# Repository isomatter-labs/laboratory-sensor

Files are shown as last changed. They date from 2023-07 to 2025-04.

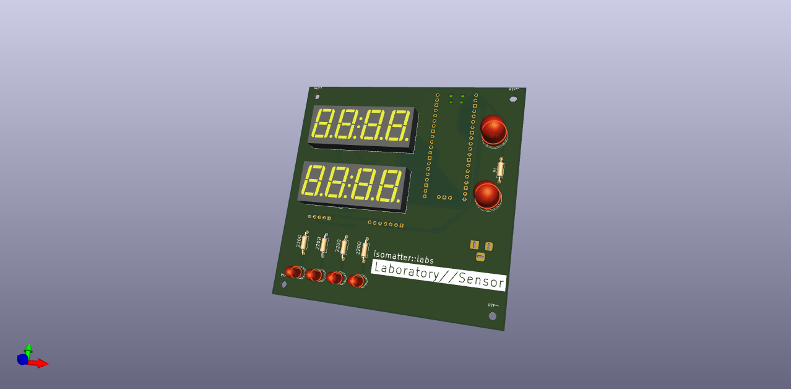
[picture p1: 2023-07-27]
hardware/printed_circuit_board/render.png

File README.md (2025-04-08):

# isomatter-labs :: Laboratory Sensor

## Software
### Building
To build the firmware for the Laboratory Sensor, execute the following:
```sh
cd build
./build.sh
```

### Flashing
After building, there should be a `.uf2` file that can be dragged-and-dropped into a Raspberry Pi Pico.
This is the entirety of the firmware, and requires no additional steps.

## Electronics
### Editing
KiCAD files can be found in `hardware/printed_circuit_board/kicad_files`,
and can be edited or modified to provide any changes you wish to the hardware or layout.

(note that changing the overall footprint of the PCB will likely require changes to the enclosure files)

### Printing
Many PCB-printing services require only `gbr` files, which can be found at
`hardware/printed_circuit_board/gbr_files`.

These files can also be re-generated using the above mentioned KiCAD files and a working copy of KiCAD.

## Enclosure
Included in `hardware/enclosure` are a series of `.step` files, with one file per part.
These files can be sliced by most, if not all, slicers, and are a bit more resilient to paywalling by various CAD editors.

Also included is a file `render.png`, which should give a good idea of what the parts should look like,
and how they should fit together to form the enclosure.

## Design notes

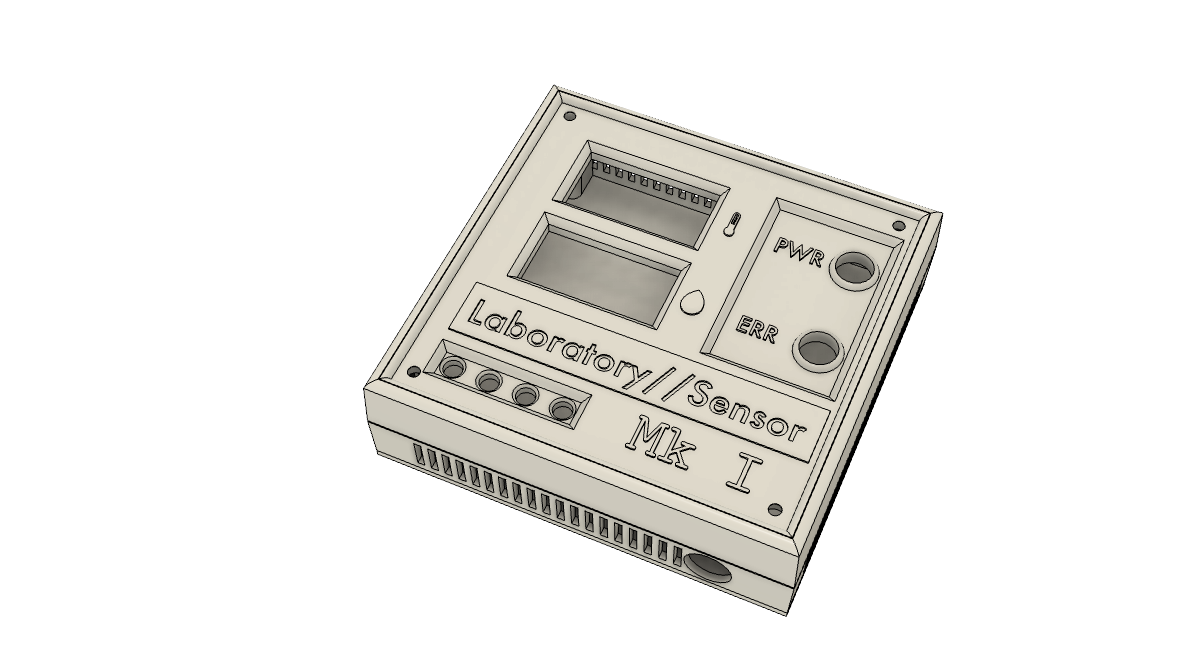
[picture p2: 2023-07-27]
hardware/enclosure/render.png

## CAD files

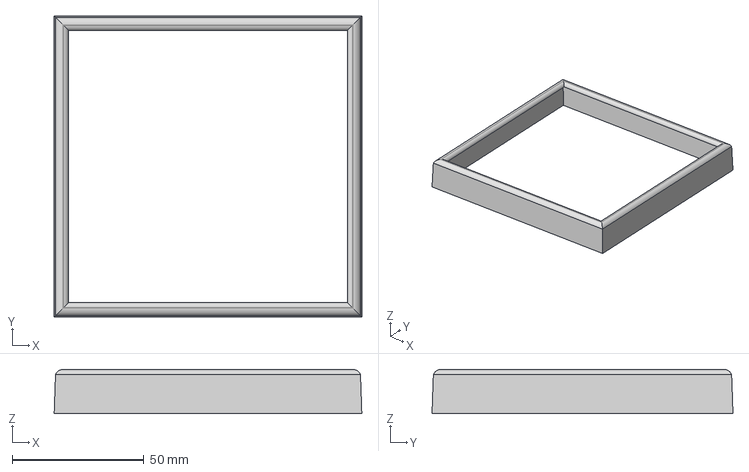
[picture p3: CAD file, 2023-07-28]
hardware/enclosure/case-top.step
116.7 x 114.2 x 16.8 mm

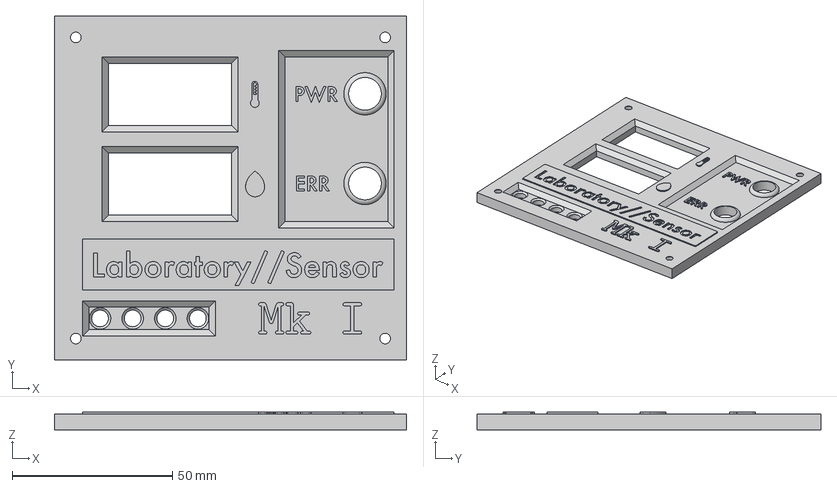
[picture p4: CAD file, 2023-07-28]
hardware/enclosure/faceplate.step
109.7 x 107.1 x 5.50 mm

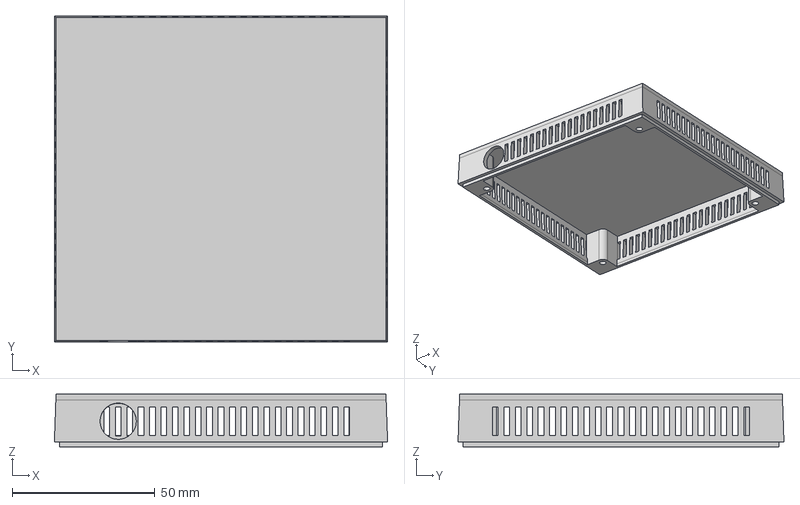
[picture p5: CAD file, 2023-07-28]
hardware/enclosure/case-bottom.step
116.7 x 114.2 x 18.5 mm

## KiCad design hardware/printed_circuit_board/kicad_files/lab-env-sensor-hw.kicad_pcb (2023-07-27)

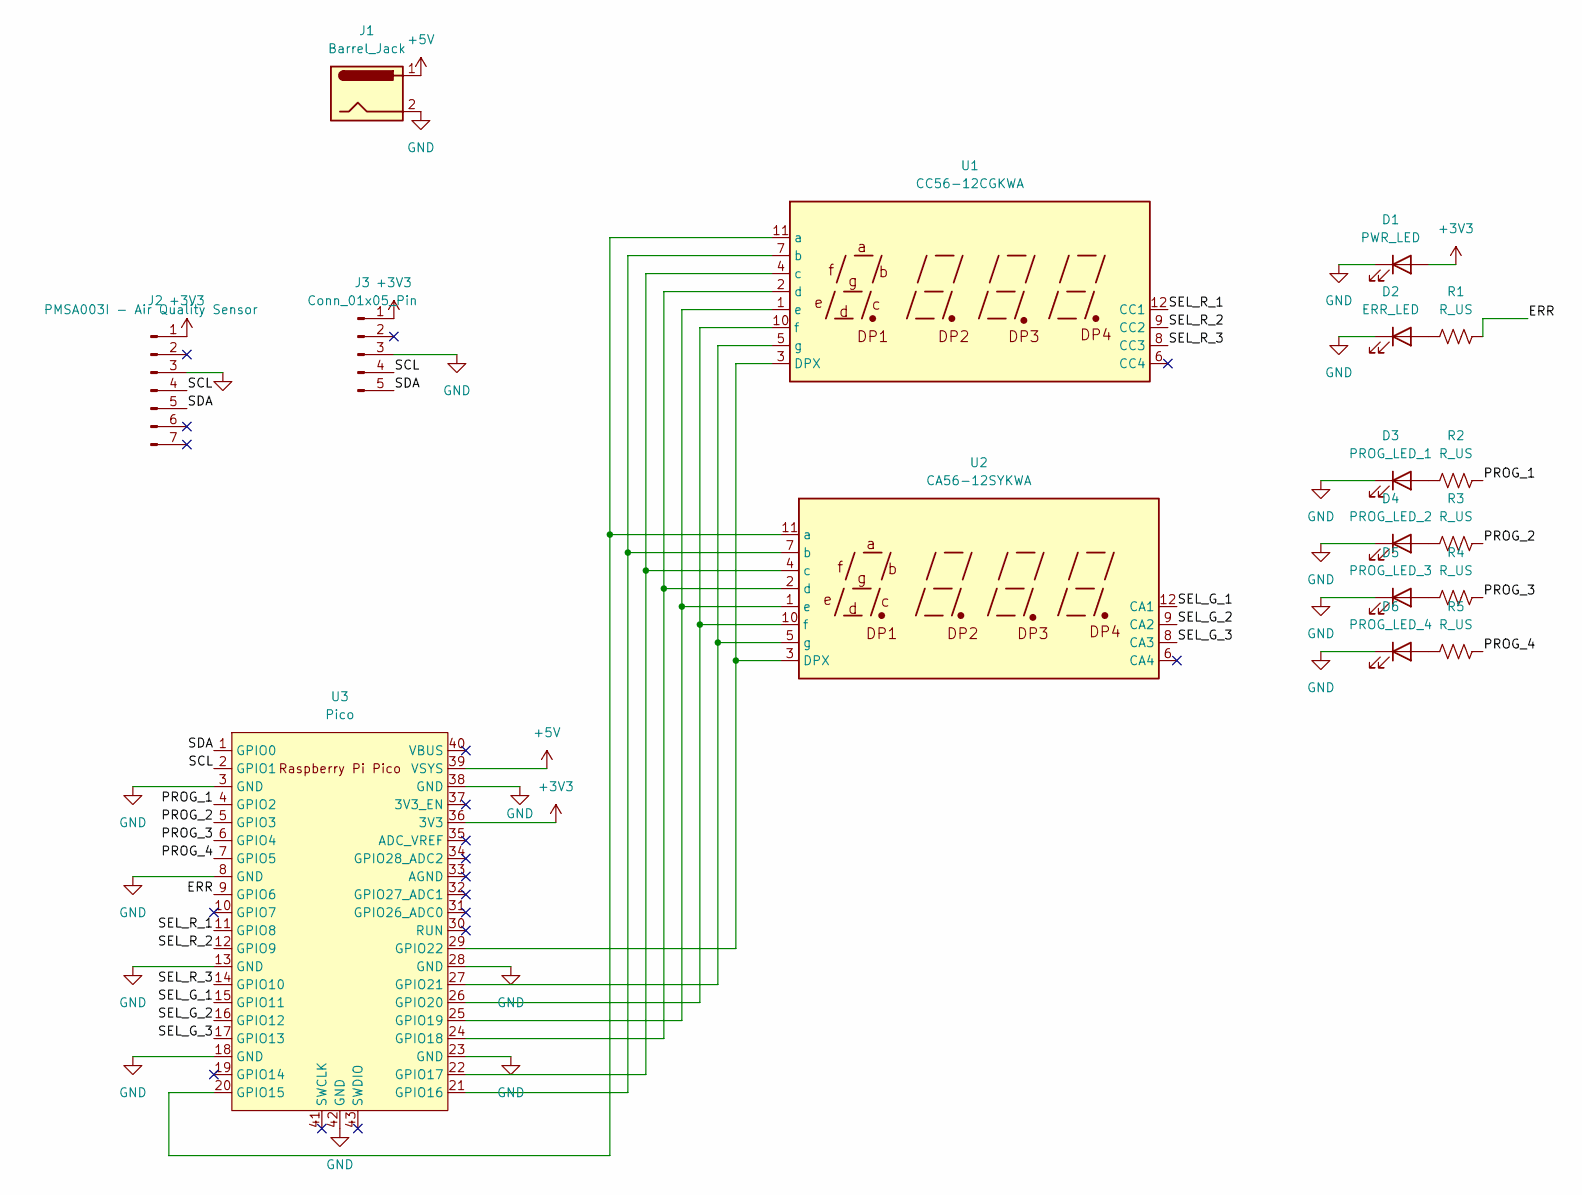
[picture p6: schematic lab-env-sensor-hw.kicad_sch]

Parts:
D1: PWR_LED; LED_D10.0mm
D2: ERR_LED; LED_D10.0mm
D3: PROG_LED_1; LED_D5.0mm
D4: PROG_LED_2; LED_D5.0mm
D5: PROG_LED_3; LED_D5.0mm
D6: PROG_LED_4; LED_D5.0mm
J1: Barrel_Jack; BarrelJack_Horizontal
J2: PMSA003I - Air Quality Sensor; PinSocket_1x07_P2.54mm_Vertical
J3: Conn_01x05_Pin; PinHeader_1x05_P2.54mm_Vertical
R1, R2, R3, R4, R5: R_US; R_Axial_DIN0207_L6.3mm_D2.5mm_P10.16mm_Horizontal
U1: CC56-12CGKWA; CA56-12CGKWA
U2: CA56-12SYKWA
U3: Pico; RPi_Pico_SMD_TH

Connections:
+3V3: D1.2 (A), J2.1 (VIN), J3.1, U3.36 (3V3)
+5V: J1.1, U3.39 (VSYS)
/ERR: R1.2, U3.9 (GPIO6)
/PROG_1: R2.2, U3.4 (GPIO2)
/PROG_2: R3.2, U3.5 (GPIO3)
/PROG_3: R4.2, U3.6 (GPIO4)
/PROG_4: R5.2, U3.7 (GPIO5)
/SCL: J2.4 (SCL), J3.4, U3.2 (GPIO1)
/SDA: J2.5 (SDA), J3.5, U3.1 (GPIO0)
/SEL_G_1: U2.12 (CA1), U3.15 (GPIO11)
/SEL_G_2: U2.9 (CA2), U3.16 (GPIO12)
/SEL_G_3: U2.8 (CA3), U3.17 (GPIO13)
/SEL_R_1: U1.12 (CC1), U3.11 (GPIO8)
/SEL_R_2: U1.9 (CC2), U3.12 (GPIO9)
/SEL_R_3: U1.8 (CC3), U3.14 (GPIO10)
GND: D1.1 (K), D2.1 (K), D3.1 (K), D4.1 (K), D5.1 (K), D6.1 (K), J1.2, J2.3 (GND), J3.3, U3.3 (GND), U3.8 (GND), U3.13 (GND), U3.18 (GND), U3.23 (GND), U3.28 (GND), U3.38 (GND), U3.42 (GND)
unnamed: D2.2 (A), R1.1
unnamed: D3.2 (A), R2.1
unnamed: D4.2 (A), R3.1
unnamed: D5.2 (A), R4.1
unnamed: D6.2 (A), R5.1
unnamed: U1.3 (DPX), U2.3 (DPX), U3.29 (GPIO22)
unnamed: U1.11 (a), U2.11 (a), U3.20 (GPIO15)
unnamed: U1.7 (b), U2.7 (b), U3.21 (GPIO16)
unnamed: U1.4 (c), U2.4 (c), U3.22 (GPIO17)
unnamed: U1.2 (d), U2.2 (d), U3.24 (GPIO18)
unnamed: U1.1 (e), U2.1 (e), U3.25 (GPIO19)
unnamed: U1.10 (f), U2.10 (f), U3.26 (GPIO20)
unnamed: U1.5 (g), U2.5 (g), U3.27 (GPIO21)

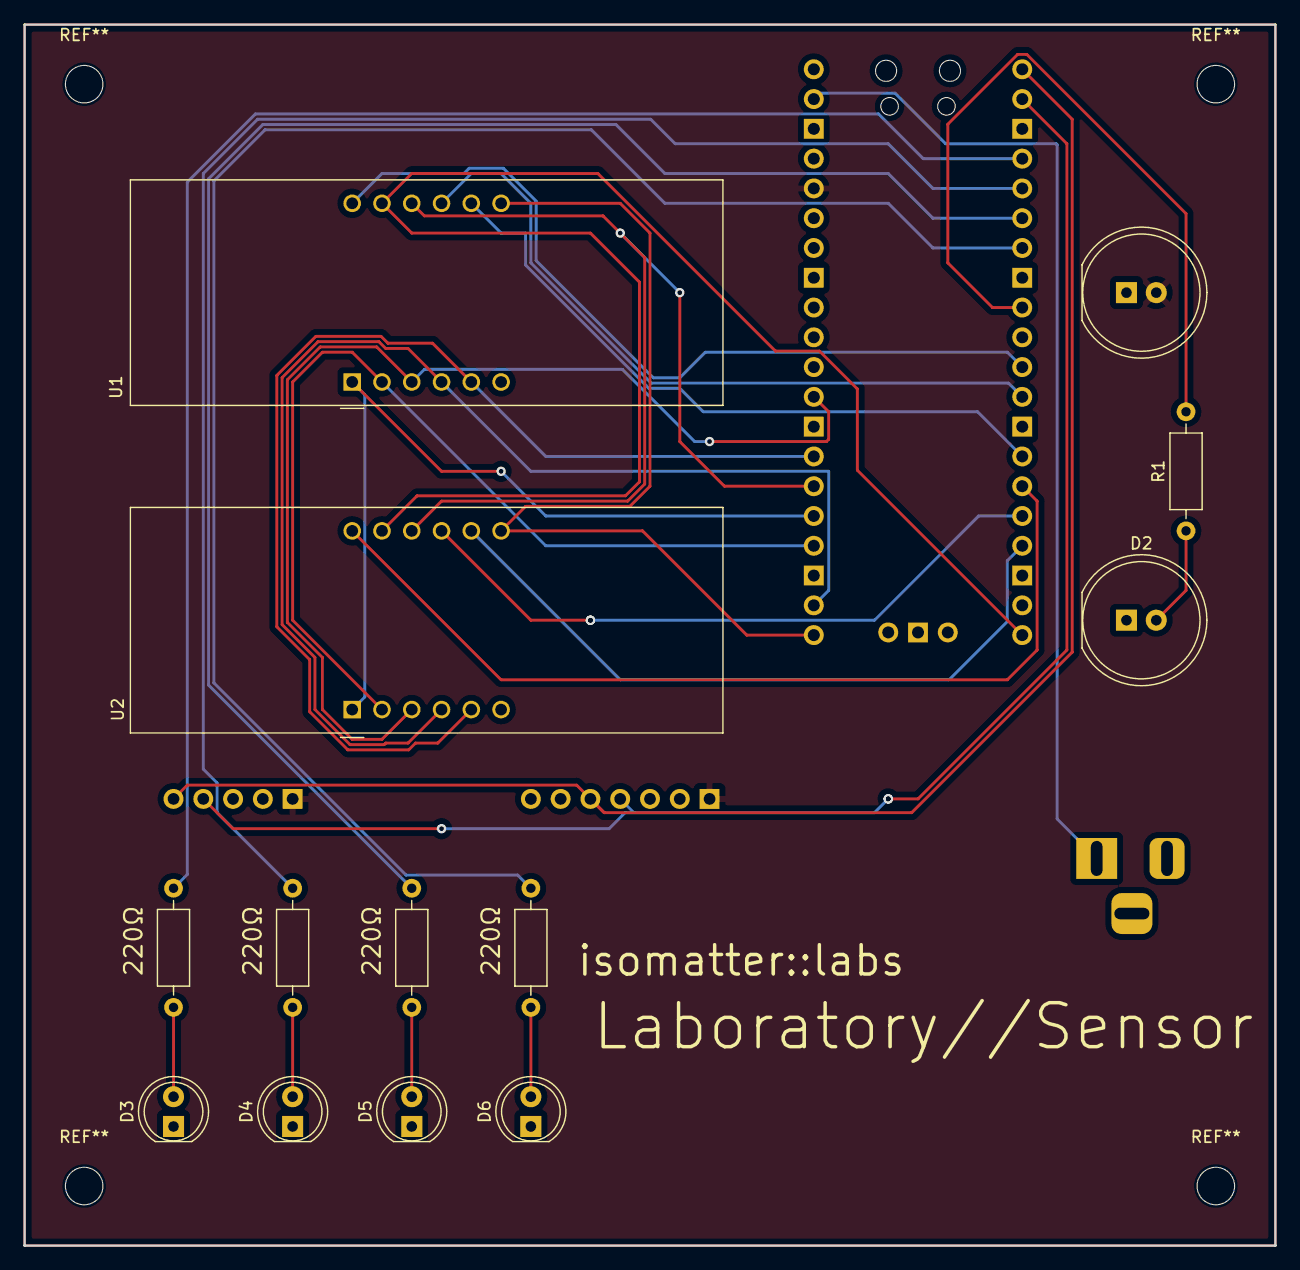
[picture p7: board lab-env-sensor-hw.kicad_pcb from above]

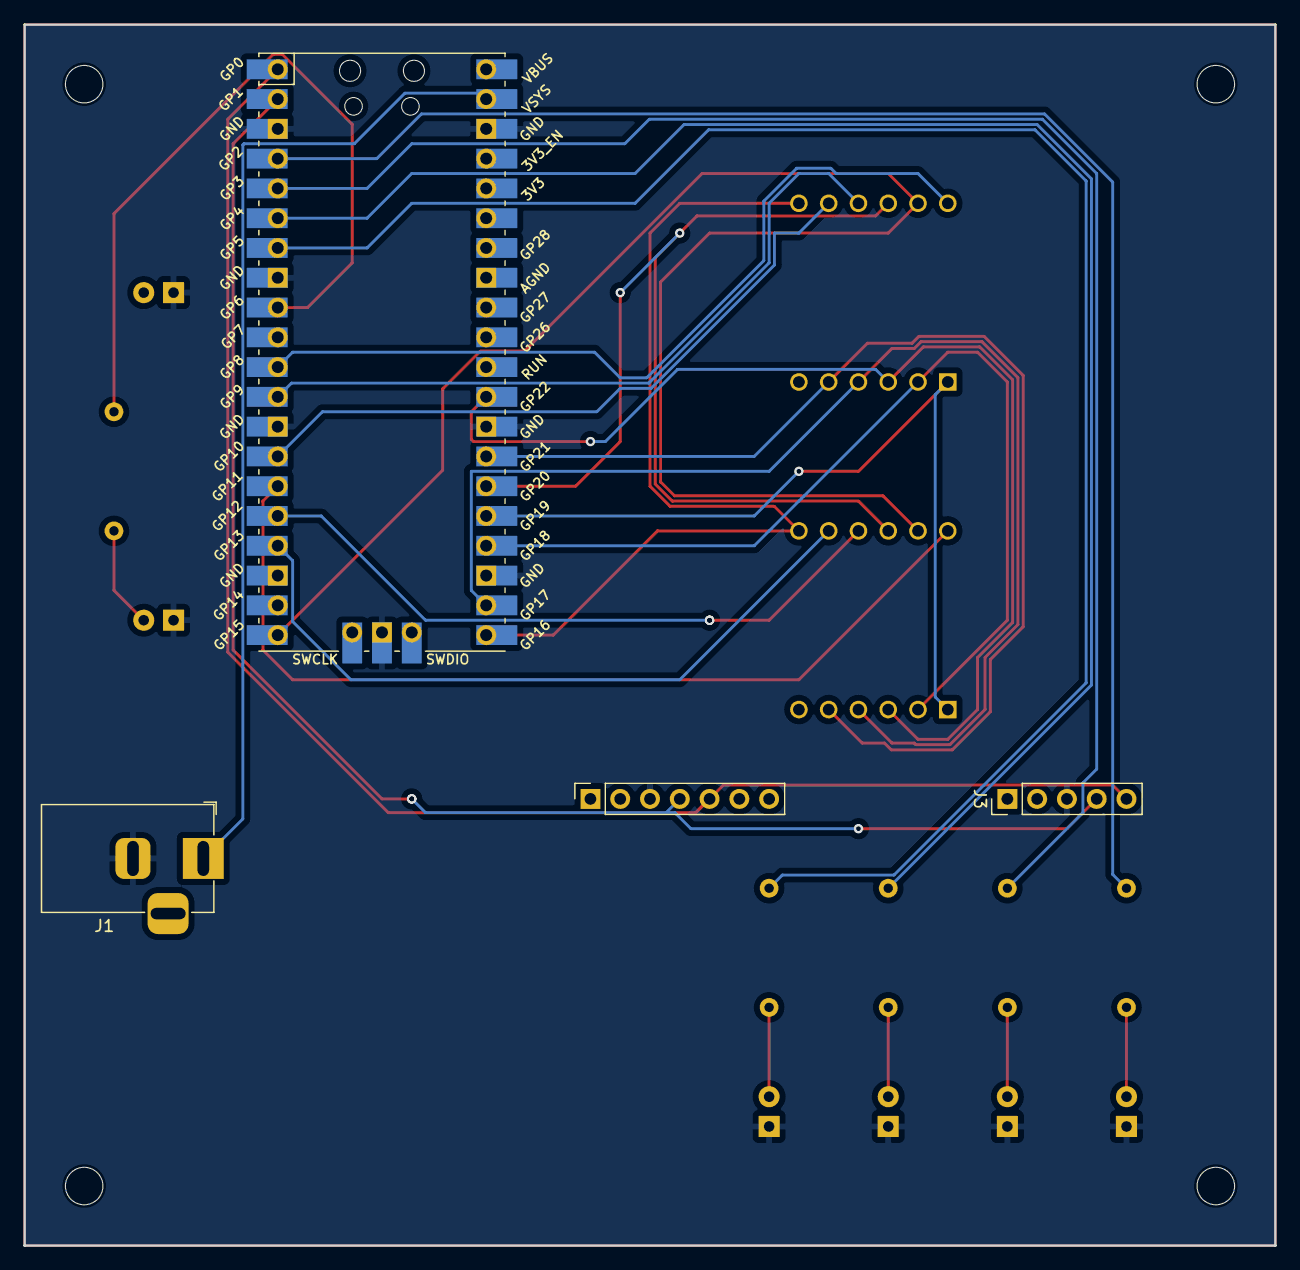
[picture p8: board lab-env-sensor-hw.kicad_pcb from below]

Board: 2 copper layers, 106.7 x 104.1 mm, 17 parts (4 on the bottom side), 29 nets.

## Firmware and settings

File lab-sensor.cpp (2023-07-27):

#include "lab-sensor.h"
#include "hardware/i2c.h"
#include "lib/Si7021/src/si7021.h"
#include "pico/stdlib.h"
#include "pico/multicore.h"
#include <iostream>
#include <stdio.h>


//     A
//   F   B
//     G
//   E   C
//     D  DP

// 0: - - F E D C B A | 0b00111111 | 0b11000000 | 0xC0
// 1: - - - - - C B - | 0b00000110 | 0b11111001 | 0xF9
// 2: - G - E D - B A | 0b01011011 | 0b10100100 | 0xA4
// 3: - G - - D C B A | 0b01001111 | 0b10110000 | 0xB0
// 4: - G F - - C B - | 0b01100110 | 0b10011001 | 0x99
// 5: - G F - D C - A | 0b01101101 | 0b10010010 | 0x92
// 6: - G F E D C - - | 0b01111100 | 0b10000011 | 0x83
// 7: - - - - - C B A | 0b00000111 | 0b11111000 | 0xF8
// 8: - G F E D C B A | 0b01111111 | 0b10000000 | 0x80
// 9: - G F - - C B A | 0b01100111 | 0b10011000 | 0x98


const int digits[10] = {0x3F, 0x06, 0x5B, 0x4f, 0x66, 0x6D, 0x7C, 0x07, 0x7F, 0x67};
const int selector_pins[2][3] = {/* GRN ENABLE */
                                 {0b00111100,
                                  0b01011100,
                                  0b10011100},
                                 /* RED ENABLE */
                                 {0b00011000,
                                  0b00010100,
                                  0b00001100}};

static int readouts[2][3] = {{0, 0, 0}, {0, 0, 0}};

int main() {
  int progress_pins[] = {-1, PROG_1, PROG_2, PROG_3, PROG_4};
  stdio_init_all();

  // Initialize the port for 7-segment display
  for (int pin_num = SEL; pin_num < SEL+8; pin_num++) {
    gpio_init(pin_num);
    gpio_set_dir(pin_num, GPIO_OUT);
  }

  for (int pin_num = DATA; pin_num < DATA+8 + 1; pin_num++) {
    gpio_init(pin_num);
    gpio_set_dir(pin_num, GPIO_OUT);
  }

  gpio_init(LED);
  gpio_set_dir(LED, GPIO_OUT);

  gpio_init(ERR);
  gpio_set_dir(ERR, GPIO_OUT);

  gpio_init(BUZZ);
  gpio_set_dir(BUZZ, GPIO_OUT);

  for (int i = 1; i < 5; i++) {
    gpio_init(progress_pins[i]);
    gpio_set_dir(progress_pins[i], GPIO_OUT);
  }

  i2c_init(i2c0, 100000);
  gpio_set_function(SDA, GPIO_FUNC_I2C);
  gpio_set_function(SCL, GPIO_FUNC_I2C);
  gpio_pull_up(SDA);
  gpio_pull_up(SCL);

  Si7021::Si7021 si7021(i2c0);
  si7021.setResolution(Si7021::Resolution::RH11T11);

  multicore_launch_core1(display_digits);
  
  bool toggle = false;
  for (;;) {
    gpio_put(PROG_1, 0);
    gpio_put(PROG_2, 0);
    gpio_put(PROG_3, 0);
    gpio_put(PROG_4, 0);
    gpio_put(ERR, toggle);
    for (int progress = 0; progress < 5; progress++) {
      gpio_put(LED, 1);
      if (progress)
        gpio_put(progress_pins[progress], 1);
      float temp_adjusted = (si7021.askForTemperature() * 1.8) + 32;
      float humidity_adjusted = si7021.askForHumidity();
      gpio_put(ERR, (temp_adjusted >= 100));
      parse_digits(RED, temp_adjusted);
      parse_digits(GRN, humidity_adjusted);

      printf("-----------------------------------------------------\n");
      printf("Si7021 Humidity: %.2f[%%]\n", humidity_adjusted);
      printf("Si7021 Temperature: %.2f[°F]\n", temp_adjusted);
      printf("-----------------------------------------------------\n");

      gpio_put(LED, 0);

      // pause before polling again
      sleep_ms(1000);
    }
    toggle = !toggle;
  }
}

void parse_digits(display_t display, float raw_val) {
  int val = (int)(raw_val* 10);
  if (val >= 1000) {
    val = 990;
  }
  readouts[display][0] = (val / 100) % 10;
  readouts[display][1] = (val / 10) % 10;
  readouts[display][2] = val % 10;
}

void write_to_data(uint8_t byte) {
  for (int i = 0; i < 8; i++) {
    gpio_put(DATA + i, (byte >> i) & 1);
  }
}

// top two bits EXPECTED to be 0
void write_to_sel(uint8_t byte) {
  for (int i = 0; i < 8; i++) {
    gpio_put(SEL + i, (byte >> i) & 1);
  }
}

void err() {
  gpio_put(ERR, 1);
  for (;;) {
    gpio_put(BUZZ, 1);
    sleep_ms(500);
    gpio_put(BUZZ, 0);
    sleep_ms(1000);

  }
}

void display_digits() {
  for (;;) {

      for (int i = 0; i < 3; i++) {
        for (int d = 0; d < END; d++) {
          int digit = digits[readouts[d][i]];
          if (i == 1) {
            digit |= 0b10000000;
          }

          if (d == GRN) {
            digit = ~digit;
          }
          write_to_sel(selector_pins[d][i]);
          write_to_data(digit);
          sleep_ms(DELAY_TIME);
        }
      }

  }
}

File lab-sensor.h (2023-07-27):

#ifndef LAB_SENSOR_H
#define LAB_SENSOR_H

#include <inttypes.h>

#define DELAY_TIME 3

/* PINS */
#define LED 25
#define ERR 6
#define BUZZ 7
#define SDA 0
#define SCL 1
#define PROG_1 2
#define PROG_2 3
#define PROG_3 4
#define PROG_4 5
/* END PINS */

/* PORTS */
#define DATA 15

#define SEL 6
/* END PORTS */

enum display_t {
  GRN,
  RED,
  END,
};

void err();
void write_to_data(uint8_t byte);
void write_to_sel(uint8_t byte);
void parse_digits(display_t display, float raw_val);
void display_digits();

#endif

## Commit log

2023-07-27 Add hardware
    [case-bottom.step, case-top.step, faceplate.step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]
2023-07-27 Add 3mf file
    [enclosure.3mf]
2023-07-27 Add render, rather than 3mf
    [enclosure.3mf]
2023-07-27 Add PCB render
2023-07-28 Update enclosure
    [case-bottom.step, case-top.step, faceplate.step]
